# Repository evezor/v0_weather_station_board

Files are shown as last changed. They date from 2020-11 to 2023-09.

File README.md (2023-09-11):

# weather_station_board
*please note this board is has been deprecated.

This board uses the Evezor Stamp STMF405 MCU

source: https://github.com/evezor/Evezor-Stamp-STMF405

This weather station board features a barometric pressure sensor, an ambient light sensor and a temerature and humidity sensor. 

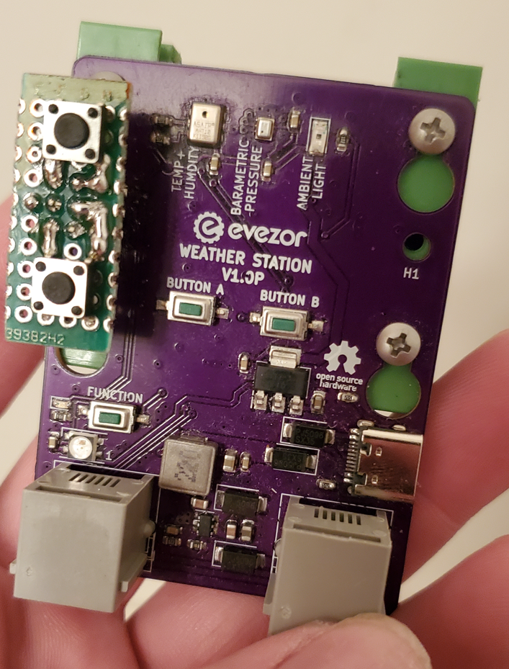
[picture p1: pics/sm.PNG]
sm


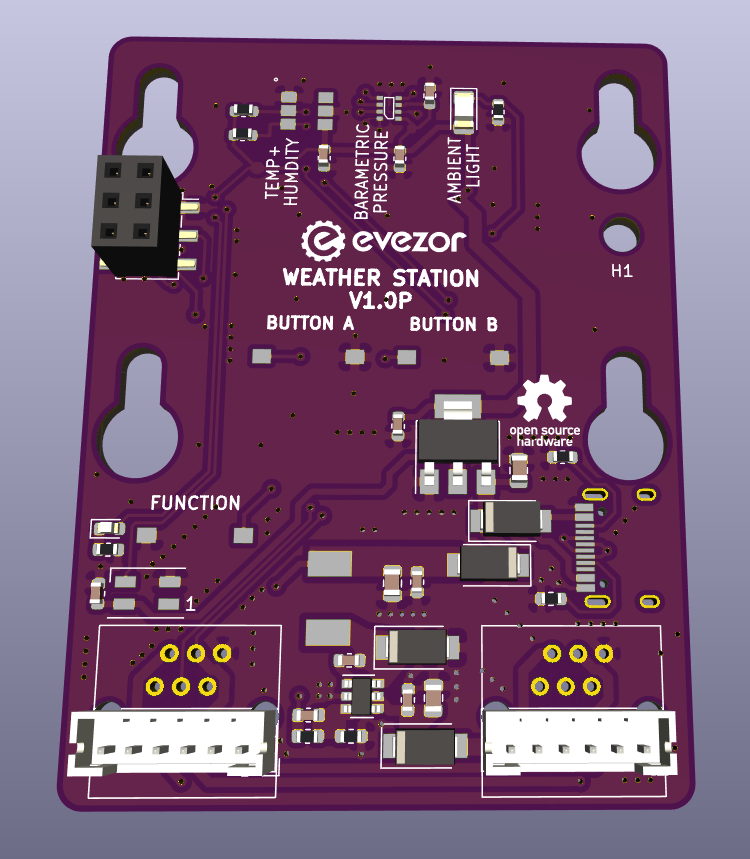
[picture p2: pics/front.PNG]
front


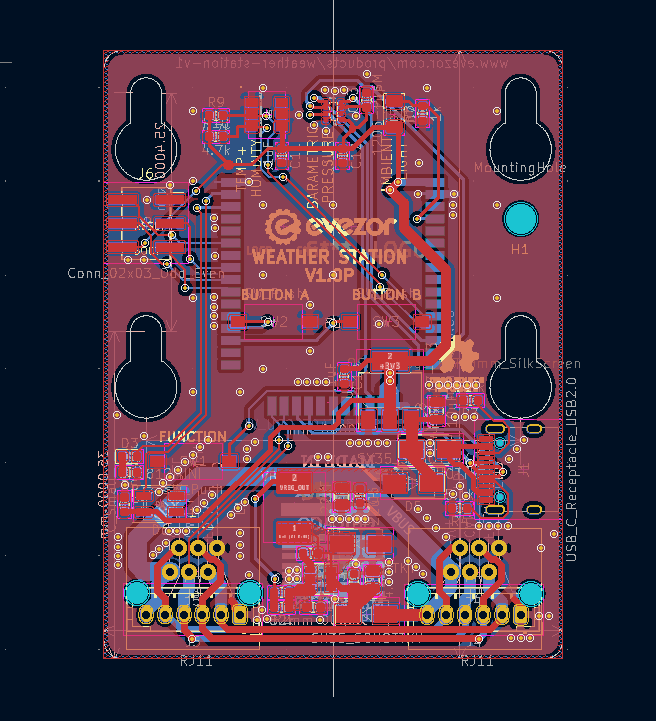
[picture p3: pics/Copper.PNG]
copper


sch

Evezor® and all associated marks, logos, and designs are registered trademarks and protected by copyright. Unauthorized use or reproduction of these trademarks and copyrighted materials is strictly prohibited

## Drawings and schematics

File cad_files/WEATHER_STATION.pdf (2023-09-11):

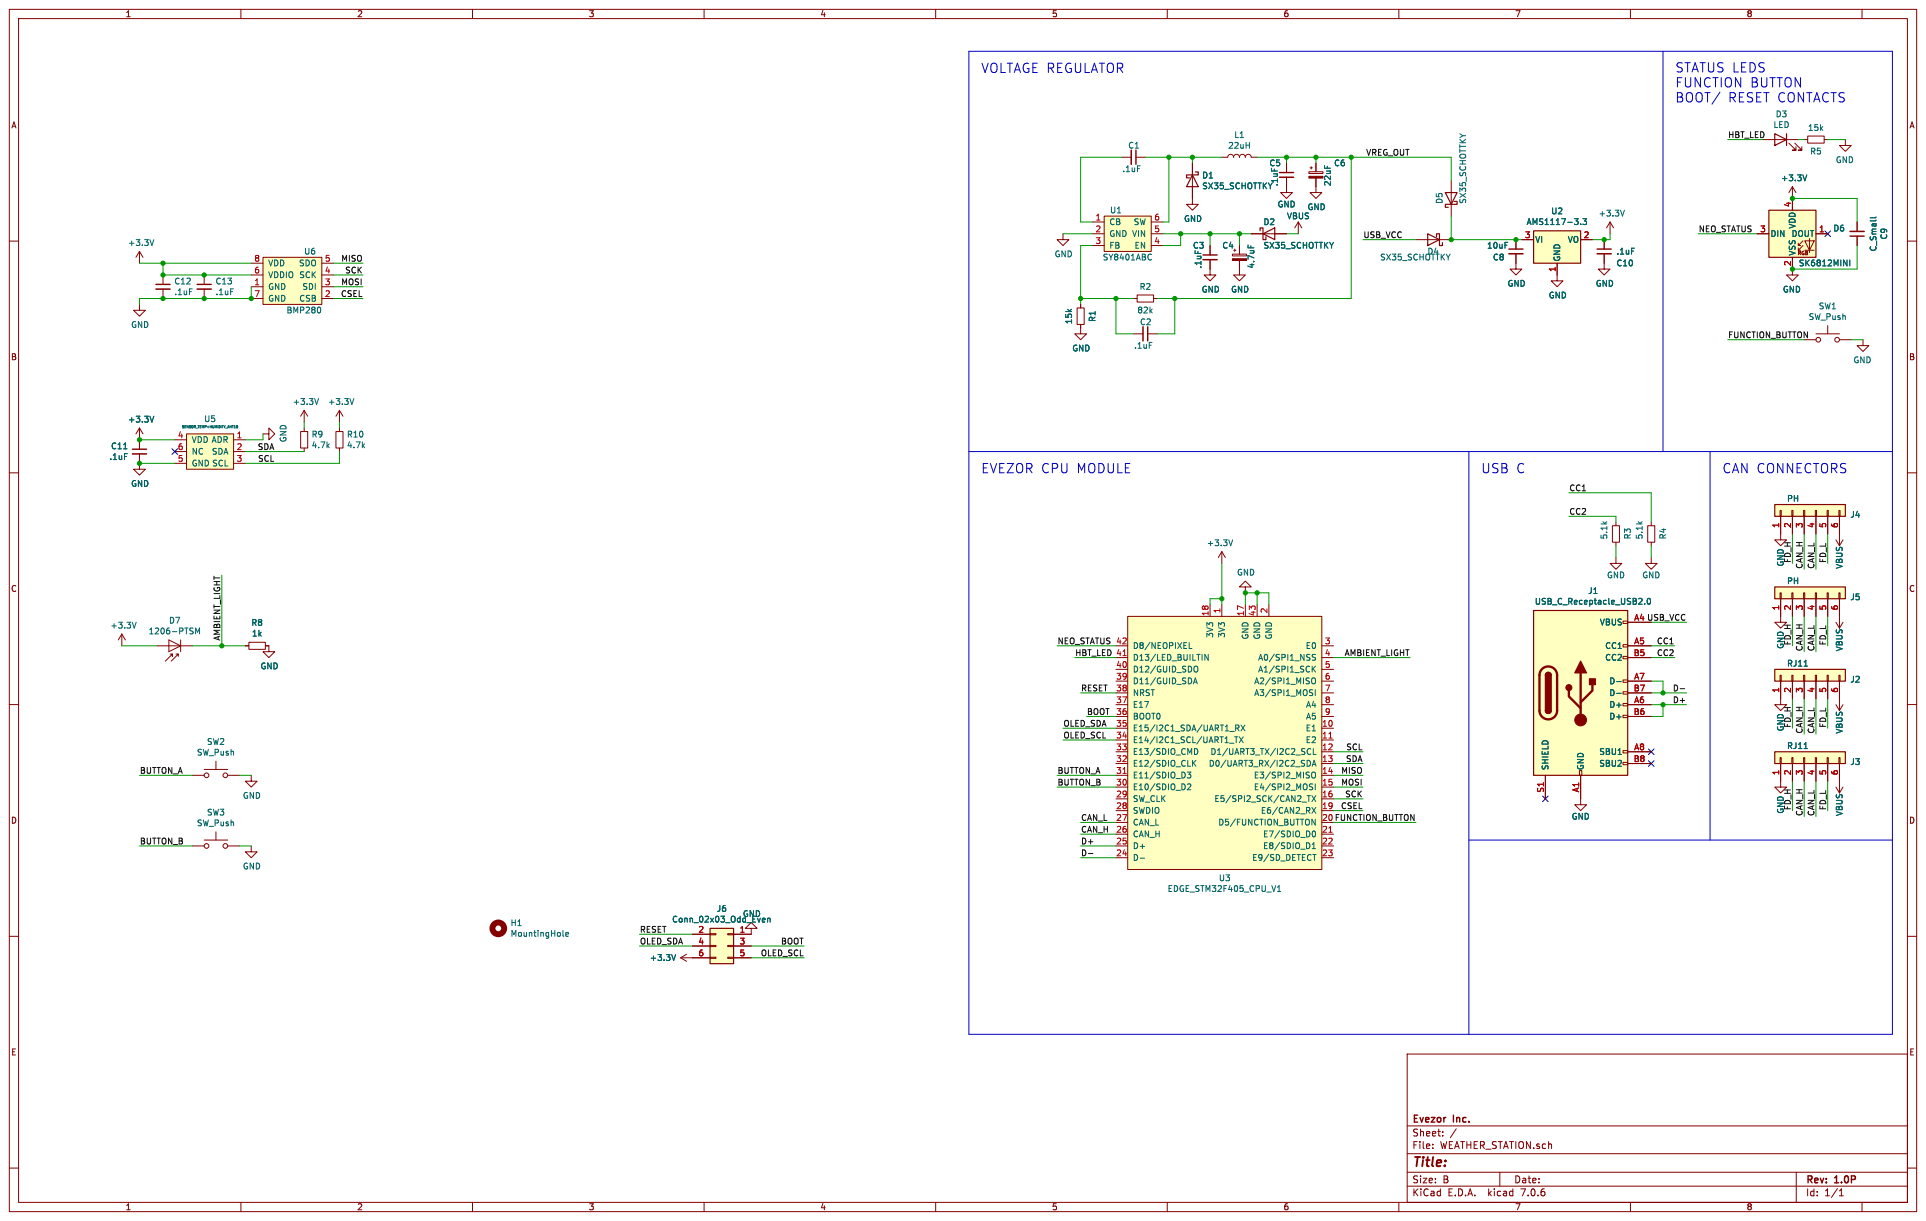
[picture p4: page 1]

2 D5/FUNCTION_BUTTON 20 E7/SDIO_D0 21 E8/SDIO_D1 22 E9/SD_DETECT 23 D- 24 D+ 25 CAN_H 26 CAN_L 27 SWDIO 28 SW_CLK 29 E0 3 E10/SDIO_D2 30 E11/SDIO_D3 31 E12/SDIO_CLK 32 E13/SDIO_CMD 33 E14/I2C1_SCL/UART1_TX 34 E15/I2C1_SDA/UART1_RX 35 BOOT0 36 E17 37 NRST 38 D11/GUID_SDA 39 A0/SPI1_NSS 4 D12/GUID_SDO 40 D13/LED_BUILTIN 41 D8/NEOPIXEL 42 GND 43 A1/SPI1_SCK 5 A2/SPI1_MISO 6 A3/SPI1_MOSI 7 A4 8 A5 9 U3 EDGE_STM32F405_CPU_V1 SW2 SW_Push GND GND GND VBUS GND

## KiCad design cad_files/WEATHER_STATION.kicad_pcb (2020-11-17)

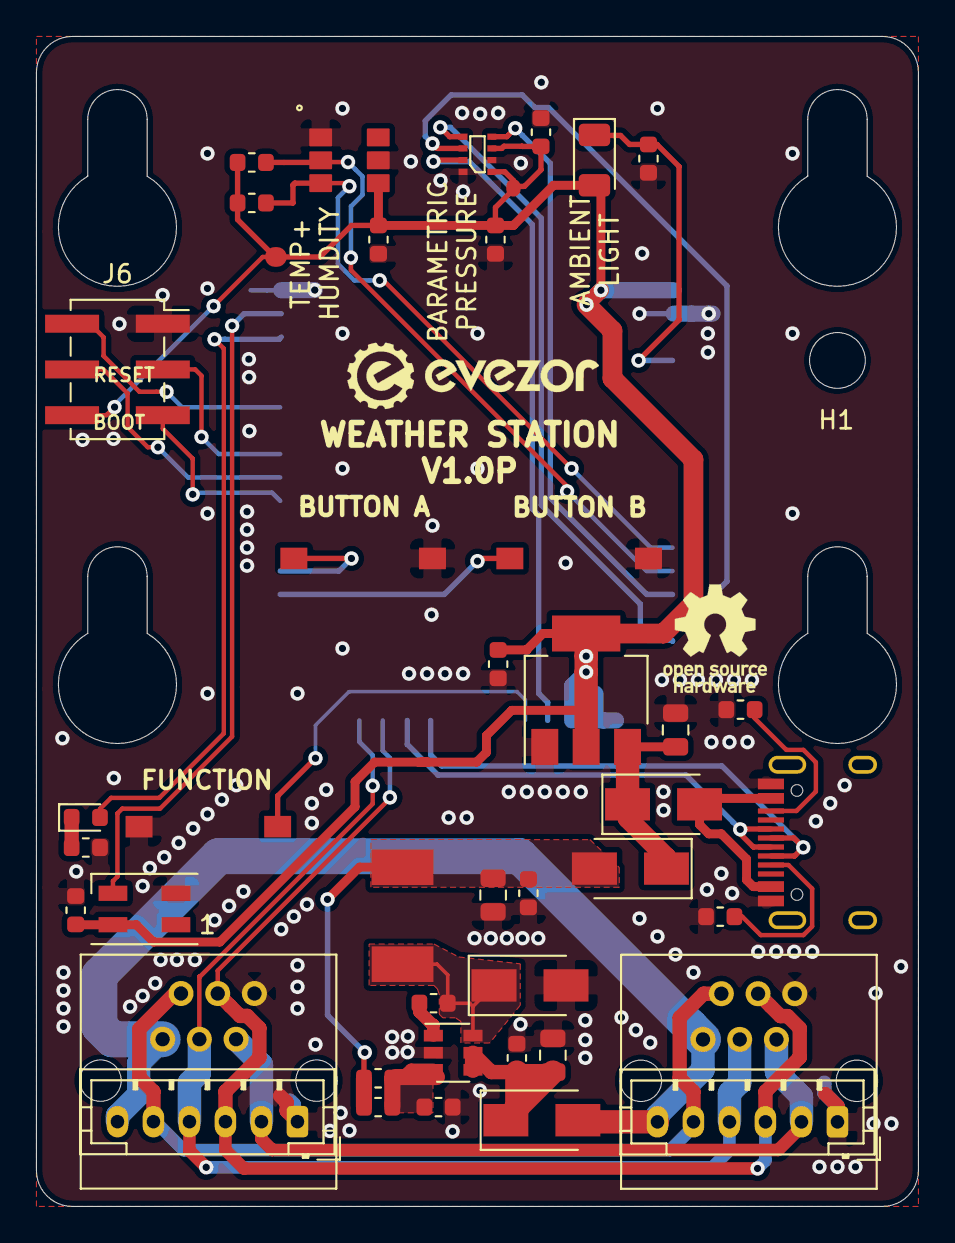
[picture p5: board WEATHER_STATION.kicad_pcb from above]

Board: 2 copper layers, 49.0 x 65.0 mm, 43 parts (1 on the bottom side), 35 nets.

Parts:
C1, C2, C3, C5, C10, C11, C12, C13: .1uF; C_0603_1608Metric
C4: 4.7uF; C_0805_2012Metric
C6: 22uF; C_0805_2012Metric
C8: 10uF; C_0805_2012Metric
C9: C_Small; C_0603_1608Metric
D1, D2, D4, D5: SX35_SCHOTTKY; D_SMA
D3: LED; LED_0603_1608Metric
D6: SK6812MINI; LED_SK6812MINI_PLCC4_3.5x3.5mm_P1.75mm
D7: 1206-PTSM; LED_1206_3216Metric
H1: MountingHole; OLED_STANDOFF
J1: USB_C_Receptacle_USB2.0; USB_C_Receptacle_HRO_TYPE-C-31-M-12
J2, J3: RJ11; RJ11_C189747_Horizontal
J4, J5: PH; JST_PH_B6B-PH-K_1x06_P2.00mm_Vertical
J6: Conn_02x03_Odd_Even; OLED_HEADER
L1: 22uH; INDUCTOR_7.5X6.6_GCDA0630-220MC
R1, R5: 15k; R_0603_1608Metric
R2: 82k; R_0603_1608Metric
R3, R4: 5.1k; R_0603_1608Metric
R8: 1k; R_0603_1608Metric
R9, R10: 4.7k; R_0603_1608Metric
SW1, SW2, SW3: SW_Push; SWITCH_2x3_SMD_TACTILE_GREEN
U1: SY8401ABC; SOT-23-6
U2: AMS1117-3.3; SOT-223-3_TabPin2
U3: EDGE_STM32F405_CPU_V1; EDGE_STAMP
U5: SENSOR_TEMP+HUMIDITY_AHT10
U6: BMP280; BOSCH_BMP280_PRESSURE_ALTIMETER

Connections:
+3V3: C9.2, C10.1, C11.1, C12.1, C13.1, D6.4, D7.2, J6.6, R9.1, R10.1, U2.2, U3.1, U3.18, U5.4, U6.6, U6.8
/AMBIENT_LIGHT: D7.1, R8.2, U3.4
/BOOT: J6.3, U3.36
/BUTTON_A: SW2.1, U3.31
/BUTTON_B: SW3.1, U3.30
/CAN_H: J2.3, J3.3, J4.3, J5.3, U3.26
/CAN_L: J2.4, J3.4, J4.4, J5.4, U3.27
/CC1: J1.A5, R4.1
/CC2: J1.B5, R3.1
/CSEL: U3.19, U6.2
/D+: J1.A6, J1.B6, U3.25
/D-: J1.A7, J1.B7, U3.24
/FD_H: J2.2, J3.2, J4.2, J5.2
/FD_L: J2.5, J3.5, J4.5, J5.5
/FUNCTION_BUTTON: SW1.1, U3.20
/HBT_LED: D3.2, U3.41
/MISO: U3.14, U6.5
/MOSI: U3.15, U6.3
/NEO_STATUS: D6.3, U3.42
/OLED_SCL: J6.5, U3.34
/OLED_SDA: J6.4, U3.35
/RESET: J6.2, U3.38
/SCK: U3.16, U6.4
/SCL: R10.2, U3.12, U5.3
/SDA: R9.2, U3.13, U5.2
/USB_VCC: D4.2, J1.A4, J1.A9, J1.B4, J1.B9
/VREG_OUT: C2.1, C5.1, C6.1, D5.2, L1.2, R2.1
GND: C3.2, C4.2, C5.2, C6.2, C8.2, C9.1, C10.2, C11.2, C12.2, C13.2, D1.2, D6.2, J1.A1, J1.A12, J1.B1, J1.B12, J2.1, J3.1, J4.1, J5.1, J6.1, R1.1, R3.2, R4.2, R5.1, R8.1, SW1.2, SW2.2, SW3.2, U1.2, U2.1, U3.2, U3.17, U3.43, U5.1, U5.5, U6.1, U6.7
unnamed: C1.1, D1.1, L1.1, U1.6
unnamed: C1.2, U1.1
unnamed: C2.2, R1.2, R2.2, U1.3
unnamed: C3.1, C4.1, D2.1, U1.4, U1.5
unnamed: C8.1, D4.1, D5.1, U2.3
unnamed: D3.1, R5.2
VBUS: D2.2, J2.6, J3.6, J4.6, J5.6

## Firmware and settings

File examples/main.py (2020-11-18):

#Weather Station v1.0p test code

from machine import Pin, I2C
from pyb import CAN, ADC, SPI
import utime


print("starting Weather Station v1.0p test code")
print("v1.0")
print("initializing")
can = CAN(1, CAN.LOOPBACK)
can.setfilter(0, CAN.LIST16, 0, (123, 124, 125, 126))


i2c = I2C(2, freq=100000)

spi = SPI(1, SPI.MASTER, baudrate=600000, polarity=1, phase=0, crc=None)


#initialize temp sensor
print("initializing AHT10 temp sensor")
utime.sleep_ms(200)
i2c.writeto(0x38, b'\xA8')
i2c.writeto(0x38, b'\x00')
i2c.writeto(0x38, b'\x00')


#Setup Pins
hbt_led = Pin("D13", Pin.OUT)
func_butt = Pin("D5", Pin.IN, Pin.PULL_UP)
can_wakeup = Pin("D6", Pin.OUT)
can_wakeup.value(0) 

barometer_cs = Pin("E6", Pin.OUT)
barometer_cs.value(1)



A_BUTTON = Pin("E11", Pin.IN, Pin.PULL_UP)  
B_BUTTON = Pin("E10", Pin.IN, Pin.PULL_UP) 
LIGHT_SENSOR = ADC("A0")

    
#Setup hbt timer
hbt_state = 0
hbt_interval = 500
start = utime.ticks_ms()
next_hbt = utime.ticks_add(start, hbt_interval)
hbt_led.value(hbt_state)


print("starting")


def chk_hbt():
    global next_hbt
    global hbt_state
    now = utime.ticks_ms()
    if utime.ticks_diff(next_hbt, now) <= 0:
        if hbt_state == 1:
            hbt_state = 0
            hbt_led.value(hbt_state)
            #print("hbt")
        else:
            hbt_state = 1
            hbt_led.value(hbt_state)  
        
        next_hbt = utime.ticks_add(next_hbt, hbt_interval)

def chk_buttons():
    global next_button_chk
    now = utime_ms()
    if utime.ticks_diff(next_button_chk, now) <= 0:
        pass
        

def send():
    can.send('message!', 123)   # send a message with id 123
    
def get():
    mess = can.recv(0)
    print(mess)
        

def read_temp_and_humidity():
    i2c.writeto(0x38, b'\xAC')
    i2c.writeto(0x38, b'\x33')
    i2c.writeto(0x38, b'\x00')
    utime.sleep_ms(75)
    print(i2c.readfrom(0x38, 6))

def spi_read(address, num_read):
    buf = bytearray(num_read)
    barometer_cs.value(0)
    spi.send(address)
    spi.recv(buf)
    barometer_cs.value(0)
    print(buf)
    
def get_p():
    spi_read(0xF7, 1)

    
while True:
    chk_hbt()
    if not (func_butt.value()):
        print("function button")
        send()
        utime.sleep_ms(200)
    
    if not (A_BUTTON.value()):
        print("A button")
        print("scanning")
        print(i2c.scan())
        print("light reading:", LIGHT_SENSOR.read())
        utime.sleep_ms(200)
    if not (B_BUTTON.value()):
        print("B button read temp and humidity")
        read_temp_and_humidity()
        utime.sleep_ms(200)






        
